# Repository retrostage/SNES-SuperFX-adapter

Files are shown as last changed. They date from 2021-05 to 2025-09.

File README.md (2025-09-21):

# SNES-SuperFX-adapter
(deprecated) A simple PCB adapter that allows the use of a M29F032, AM29F032/29F016 or MBM29F033 (or other pin compatible) flash memory to make a reproduction of a SNES game that uses the SuperFX (GSU-1 or GSU-2) or CX4 cartridge type. No manual wires or hot glue!

Included is the Gerber files (and a ".brd" file that works for OSH Park) which are needed for a PCB manufacturer to actually make the boards. The PDF instructions on how to assemble are included as well.

# NEW FOR 2025
The complete source for an upgraded design that uses modern and easily obtainable flash memory that you can find from places like Digikey or Mouser, like M29F160 and similar TSOP48 chips, has been added. This is the recommended design to use, as the old one is extremely outdated and uses flash memory that can only be found used, and often at expensive prices. This design is also easier for PCB fabs to produce. This design is intended for up to M29F160 (2MB) ROM sizes, but you can use M29F800 (1MB), or M29F400 (512KB) chips instead if your game is less than 2MB - or just double-up the ROM data with a hex editor and use the M29F160 for any game.

You can use EAGLE CAD or a compatible CAD program to open the source and view or change the design. Or just use the .brd file with your PCB manufacturer, most will accept that instead of gerber files.

These boards require castellation, a PCB manufacturing process that uses "half-vias" on the board edges, to ensure easy soldering to the donor cartridge. Check with your PCB manufacturer to make sure they support this feature (most do, at a slightly higher cost). Recommended PCB thickness is 1.0mm or even 0.8mm for best results.

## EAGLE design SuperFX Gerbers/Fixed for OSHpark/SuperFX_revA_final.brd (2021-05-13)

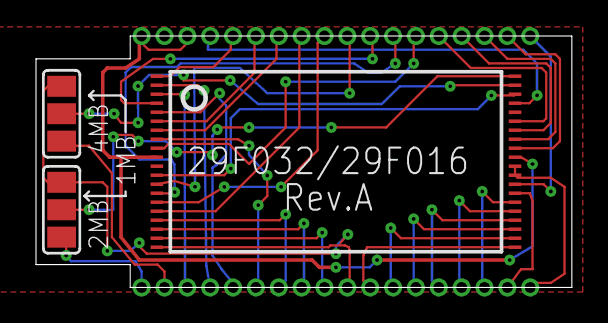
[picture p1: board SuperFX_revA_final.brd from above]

Board: 2 copper layers, 29.8 x 14.0 mm, 3 parts (0 on the bottom side), 4 nets.

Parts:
20, 21: SJ_2
U$1: AM29F032B-E; 40-TSOP

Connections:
GND: 20.3, 21.3, U$1.29, U$1.30
unnamed: 21.2, U$1.39
unnamed: 20.2, U$1.40
VCC: U$1.10, U$1.12, U$1.31, U$1.38

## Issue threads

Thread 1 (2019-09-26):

Board outline on copper layers can result in fabrication shorts.

tekdemo, 2019-09-26:
The gerbers provided have the outline duplicated on all layers, which generates copper layer gerbers that have shorts all over the place, as shown here

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

To get the boards as intended, rather than as provided, a fab would need to detect and correct this automatically. Otherwise, the resulting board has all contacts shorted.

Of particular note, OSH Park (my employer) does not correct for this, as doing so in an automated process will interfere with boards that rely on it for various design elements.

Generally, resolving this is extremely straightforward, by simply adjusting some CAM settings. Usually it's either a single option for "put outline on all gerbers" in the main CAM setup, or by removing the outline layer for the individual layer settings.

retrostage, 2019-09-26:
Interesting. I haven't seen an issue with this before using other PCB manufacturers, and I'd been having them made for over a year at least before I put them on GitHub.

I'll take a look at the design and re-upload with your suggested change, hopefully to prevent this issue happening.

Closed 2019-09-26.

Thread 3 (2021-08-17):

GSU-2 compatibility

AndehX, 2021-08-17:
Just wondering if this adapter definitely works with GSU-2 carts, as these use 40 pin ROM's as opposed to the 32 pin ROM on the GSU-1 carts.

retrostage, 2021-08-17:
Yes, there are extra pins on the left side where the MaskROM sits that will not be soldered to the adapter pins - which is fine because they're just extra VCC and GND pins anyway. These also work in 40 pin CX4 carts like MegaMax X3.

AndehX, 2021-08-17:
cool, thanks for clarifying

AndehX, 2021-08-31:
So im trying to get this to work with Star Fox 2, but im having no luck.  I've flashed the chip properly and verified the data on it.  ucon64 confirms no header and CRC is OK, but im just getting a blank screen on my SNES.  Any ideas?
Heres some image of the install:

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

retrostage, 2021-08-31:
Looks like you've replaced the SRAM. Did you verify that it's all wired up and the correct type for SF2? Other than that, if you have a multimeter you can use the continuity mode to check each pin on the adapter/flash memory to make sure you didn't damage any pins during removal of the old maskrom.

AndehX, 2021-08-31:
Yeah I already buzzed out all the pins and they all seem fine.  This is actually the second cart I tried this one (in case the first one was messed up somehow)  The SRAM is a 1024KB chip (commonly used for Gradius III SA-1 carts)  I assume it should work ok.  Would that cause any issues? Should I put the original 256K SRAM back?

retrostage, 2021-08-31:
I'd recommend putting the old one on and test again. I'm not familiar with
changing out the SRAM on these boards, the pinout differences, or how it
affects the games that use it.

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

AndehX, 2021-08-31:
Yeah with the original SRAM, it's still the same.  I also tried padding the ROM to 2MB (to fill the 29F016 chip) no dice.  I'm literally out of ideas now.  I removed the chip, read the ROM back from the chip and it loads fine in BSNES, so i'm 95% sure I've flashed the chip properly

retrostage, 2021-08-31:
Do you have a normal GSU-1 board on hand that you can try the adapter in?

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

AndehX, 2021-08-31:
I don't unfortunately.  Only GSU-2 boards

retrostage, 2021-08-31:
Apparently SF2 requires 512K of SRAM, so the 256K you put back in won't cut it.

Have you compared the pinout of the SRAM you selected to the one the donor cart used?

AndehX, 2021-08-31:
Ok I figured it out. It seems for some odd reason GSU-2 boards (or at least the Yoshi's Island ones I have) are missing address line A15 on the SRAM.  I had to lift that address line on the SRAM and manually wire it to pin 105 of the GSU-2.  It's working now.

This might be something you want to mention in the documentation for you adapter.

retrostage, 2021-08-31:
Glad you got it figured out, and that the adapters were working fine.

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

AndehX, 2021-08-31:
Yeah.  Just really confused why SRAM A16 would be connected... but not A15.  Super weird.

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

AndehX, 2021-08-31:
I know you've closed this, and it is technically fixed (not related to the adapter) but im getting crashing now. usually after a minute or 2 of the starfox 2 intro looping.  Any ideas what could cause that?  Sometimes the 3d models disappear, other times the game just glitches and freezes

retrostage, 2021-08-31:
I'd suspect the SRAM. You're giving 1Mbit of it when the game expects only 512K. Try grounding A16 on the SRAM to see if that helps.

AndehX, 2021-08-31:
Yeah I had the same idea literally as I posted my previous comment.  Didn't seem to do anything though.

AndehX, 2021-08-31:
I'm going to leave it for tonight.  I'll try flashing the rom normally again tomorrow (without padding to 2MB)

retrostage, 2021-08-31:
Maybe try one with a game that natively uses the GSU-2 chip, like Yoshi's
Island or something. I've never made one with SF2 on a FX-2 board before,
so maybe there is some kind of issue due to the different clock speed.

I'll leave this ticket closed for now. As long as the game boots up and
plays it's not a problem with the design of the adapter itself, it's likely
some other issue at hand. But I'd be interested in hearing how things go on
your end regardless.

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

AndehX, 2021-09-01:
Ok so I did some testing tonight.  Original Star Fox runs perfectly.  Star Fox 2 still shows graphical glitching and random freezing.  Tried 2 different roms (from 2 different places) and both show the same issue.  So i'm thinking either there's an issue with the type of flash im using (29F016) or the SRAM chip im using.  I'm inclined to believe the SRAM is probably at fault.  I have some different 1Mbit chips ordered (I can't find any compatible 512Kbit chips), and I will test those when they arrive.

retrostage, 2021-09-01:
I wouldn't think the flash is at fault, as the one you used is fully
pin-compatible with the adapter (all extra unsoldered legs on your chip are
NC anyway). I'd probably suspect the SRAM too, especially if the flash data
also verified correctly.

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

AndehX, 2021-09-01:
> I'd probably suspect the SRAM too, especially if the flash data also verified correctly.
>
Yeah especially since original Starfox seems to run perfectly fine.
One difference I did notice between the GSU-1 and GSU-2 boards, is that the /CE pin is grounded on the GSU-1 board, but connects to pin 20 of the GSU-2-SP1 chip on GSU-2 boards.  Does that matter?

AndehX, 2021-09-02:
Ok so I tried a different SRAM chip today (SONY CXK581000AM) and the result is the same (although the freezing is less frequent) it seems more stable with this chip, but ultimately, it still crashes now and then and has minor graphical glitches.
It seems like i'm not going to get anywhere with this unless I can source a 512Kbit chip.

Closed 2021-08-31.

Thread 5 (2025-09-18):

PCBWay no likey

NachtRaveVL, 2025-09-18:
PCBWay big mad that these traces are too close together.

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

retrostage, 2025-09-21:
I've just updated the repo with a new design source file. You can open it with EAGLE CAD, or just use the .brd file with your PCB manufacturer. It uses modern flash memory instead of the hard-to-find AM29F032 chips.

NachtRaveVL, 2025-09-25:
So, the further I look into this, the more I think you might have missed connecting A21 into anything.

Wouldn't that mean this only supports up to 8MBit/1MB and not 16MBit/2MB?

I realize ofc that A21 is typically tied to A17 when not used, such as with StarFox 2.

retrostage, 2025-09-25:
Can this ticket be closed now @NachtRaveVL ? Since PCBway now accepts the files, and all.

NachtRaveVL, 2025-09-26:
Yeah sorry about the delete, realized I was miscounting the pins. Least significant bit of address line A0 goes into DQ15-A1 of TSOP and then A1 goes into A0 of TSOP. Address into TSOP is 16-bit since /BYTE is tied to GND and active low.

Did you want me to mail you one of the chips I get from PCBWay for your own tinkering? Lemme know if so - email above.

Feel free to close.

retrostage, 2025-09-26:
I definitely appreciate the offer, but I don't have any need for them personally.

If you're on the RetroStage Discord server, there are probably some users there that would be interested. Possibly even as a group buy.

OK, I'll close this for now. If you run into any issues once you have them feel free to open a new ticket!

Closed 2025-09-26.

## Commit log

2019-09-26 Fixed dimension outline issue that was causing shorting of all outside pins on the copper layer, affecting only OSHpark it seems.
    [SuperFX_revC.GBL, SuperFX_revC.GBO, SuperFX_revC.GBP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]
2021-05-13 Added SuperFX .brd file
    Will help with anyone getting an error at OSH Park.
    [SuperFX_revA_final.brd]
2025-09-21 Added new design
    Requires EAGLE or compatible CAD software - can use .brd file directly on most PCB manufacturer sites
    [SuperFX_revD.brd, SuperFX_revD.sch]
